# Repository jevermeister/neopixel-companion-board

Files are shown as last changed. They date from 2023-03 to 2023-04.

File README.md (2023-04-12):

# Neopixel companion board

This is a board to control and power Neopixels (WS2812 and derivatives) using a separate microcontroller.

**Please note that the board doesn't feature any fuses to keep it compact. If for whichever reasons you get a short, bad things may happen!
If in doubt, add a 5A fuse after the microfit connector for additional safety**

To reliably control and power also large strips, the board does a couple of things:

* A 1000uF capacitor for each strip to buffer initial power spikes which may cause the Neopixel controller to brownout due to voltage drops (which would cause the strip to now show anything)
* A 4.7k pulldown resistor for each microcontroller pin to make sure these pins are not floating. While most microcontrollers have integrated pulldowns which could be activated, this won't hurt and ensure a stable communication.
* A level shifter (SN74AHCT125D) as Neopixel expect 5V logic levels while most 32-bit microcontrollers have only 3.3V. Often they also work with 3.3V voltage but not always, that is why we make sure they will with a level shifter. In case you already have 5V logic level - This won't hurt at least and the level shifter is able to deal with it.
* Provide high current connectors. Each strip is connected using Molex Microfit 3.0 connectors which are rated up to 5A. The board itself is connected with screw terminals rated up to 18A.

I already put LCSC/JLCPCB part numbers in the design so you should be able to order these either assembled or know which parts to get.
Please note that I used a TE 796949-2 screw terminal on my PCB which is not available at LCSC so the one I put in there should also fit and work but I didn't test it.

How to wire it:
* Attach microcontroller pins to the JST-XH terminal labeled 1 2 3 4, these correspond to the J1 to J4 molex connectors

Best case those are pins which go straight to the microcontrollers without anything in between. I used PE7 to PE10 located at the EXP1 connector of my BigTreeTech Octopus Pro 1.0
* Attach a 5V power supply (don't try anything higher or the capacitors *will* pop) to the screw terminals, polarity is shown on the board

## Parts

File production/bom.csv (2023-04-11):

Designator | Footprint | Quantity | Value | LCSC Part #
C1, C2, C3, C4 | CP_Radial_D8.0mm_P3.50mm | 4 | 1000 uF | C106511
J1 | Molex_Micro-Fit_3.0_43650-0315_1x03_P3.00mm_Vertical | 1 | PXL_1_Output | C293546
J2 | Molex_Micro-Fit_3.0_43650-0315_1x03_P3.00mm_Vertical | 1 | PXL_2_Output | C293546
J3 | Molex_Micro-Fit_3.0_43650-0315_1x03_P3.00mm_Vertical | 1 | PXL_3_Output | C293546
J4 | Molex_Micro-Fit_3.0_43650-0315_1x03_P3.00mm_Vertical | 1 | PXL_4_Output | C293546
J5 | 796949-2 | 1 | VIN | C430601
J6 | JST_XH_B4B-XH-A_1x04_P2.50mm_Vertical | 1 | PXL_Input | C144395
R1, R2, R3, R4 | 1206 | 4 | 4.7K | C104821
U1 | SN74AHCT125D | 1 | SN74AHCT125D | C155176

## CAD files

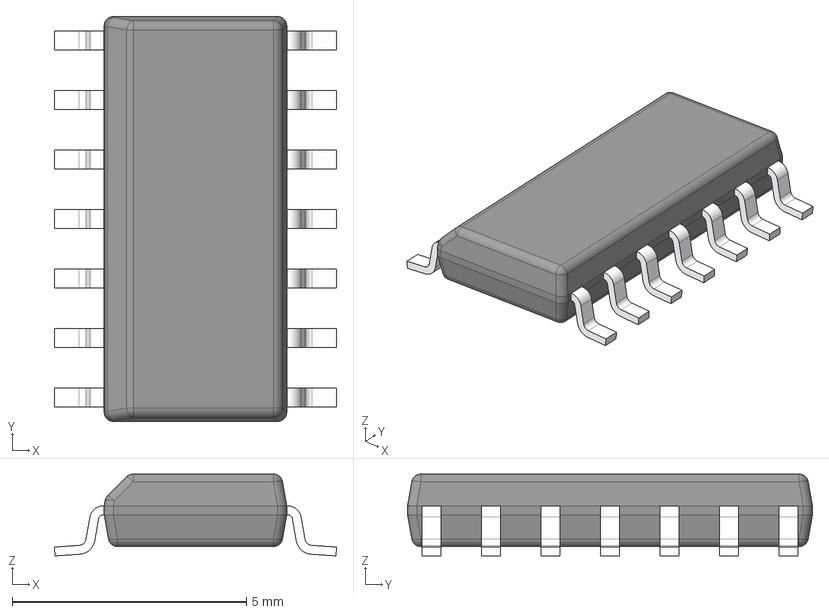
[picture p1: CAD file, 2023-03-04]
D0014A.stp
6.03 x 8.65 x 1.75 mm
BODY-SO
LEAD-SO x 14
PIN1-ID

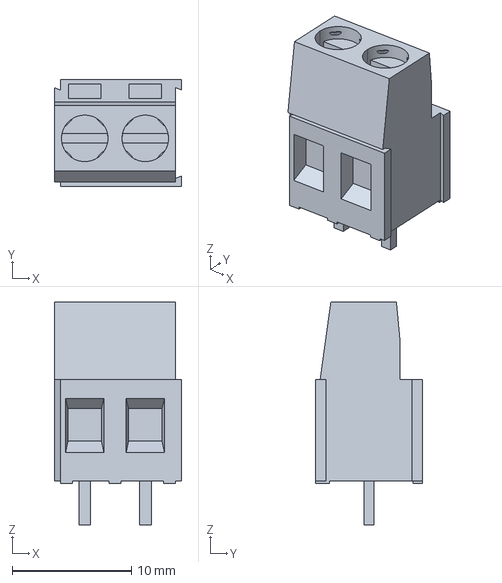
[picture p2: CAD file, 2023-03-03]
c-796949-2-c-3d.stp
10.7 x 9.00 x 18.7 mm

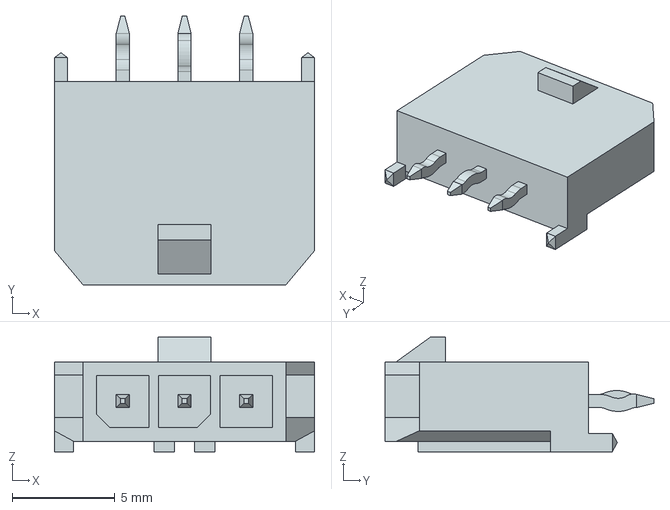
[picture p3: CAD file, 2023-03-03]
436500315.stp
12.7 x 13.1 x 5.57 mm

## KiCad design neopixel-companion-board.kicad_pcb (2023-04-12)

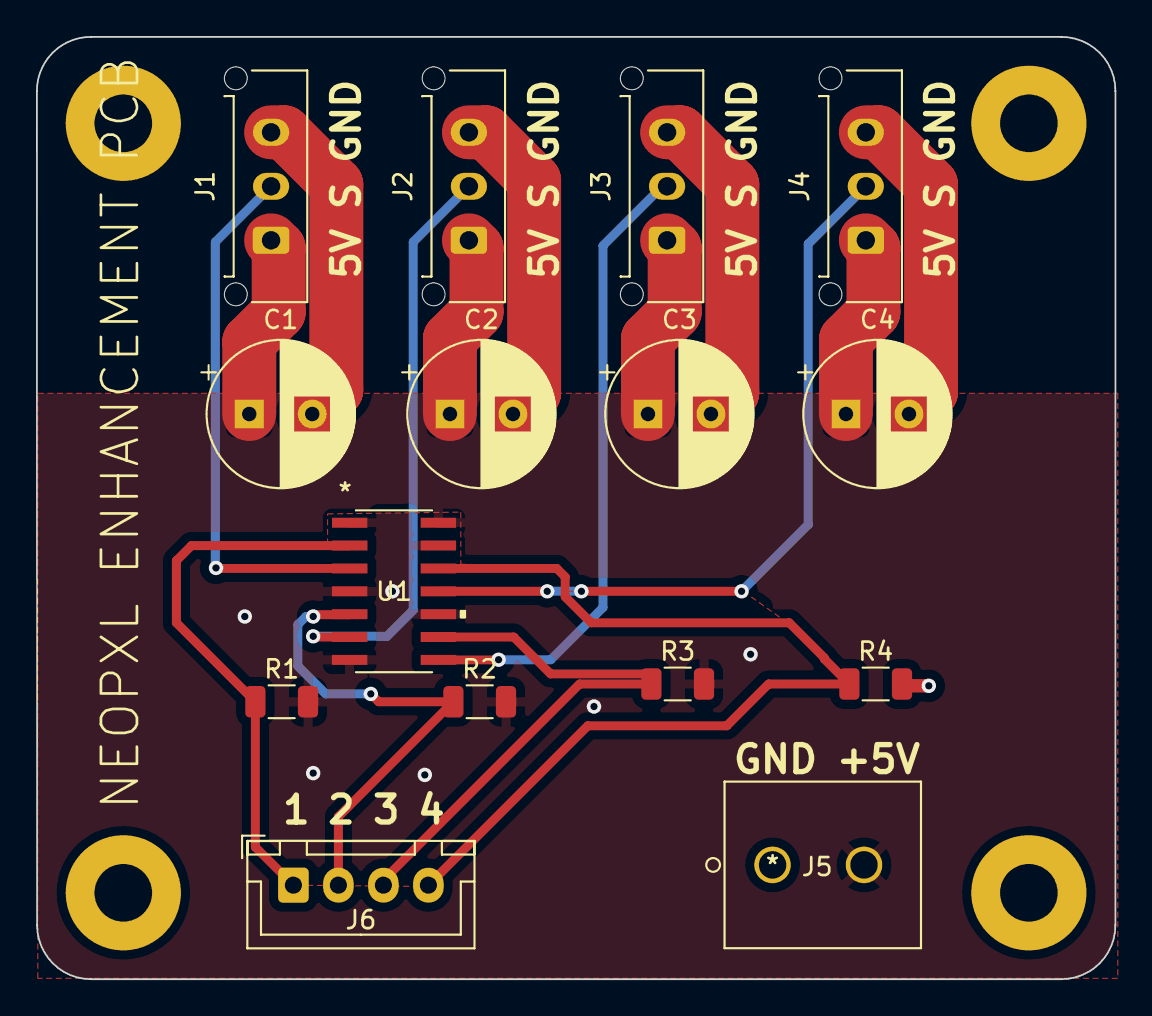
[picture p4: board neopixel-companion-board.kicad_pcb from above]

Board: 2 copper layers, 59.9 x 52.4 mm, 15 parts (0 on the bottom side), 10 nets.

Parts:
C1, C2, C3, C4: 1000 uF; CP_Radial_D8.0mm_P3.50mm
J1: PXL_1_Output; Molex_Micro-Fit_3.0_43650-0315_1x03_P3.00mm_Vertical
J2: PXL_2_Output; Molex_Micro-Fit_3.0_43650-0315_1x03_P3.00mm_Vertical
J3: PXL_3_Output; Molex_Micro-Fit_3.0_43650-0315_1x03_P3.00mm_Vertical
J4: PXL_4_Output; Molex_Micro-Fit_3.0_43650-0315_1x03_P3.00mm_Vertical
J5: VIN; 796949-2
J6: PXL_Input; JST_XH_B4B-XH-A_1x04_P2.50mm_Vertical
R1, R2, R3, R4: 4.7K; R_1206_3216Metric
U1: SN74AHCT125D

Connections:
+5V: C1.1, C2.1, C3.1, C4.1, J1.1, J2.1, J3.1, J4.1, J5.2, U1.14 (VCC)
GND: C1.2, C2.2, C3.2, C4.2, J1.3, J2.3, J3.3, J4.3, J5.1, R1.2, R2.2, R3.2, R4.2, U1.1 (*1OE), U1.4 (*2OE), U1.7 (GND), U1.10 (*3OE), U1.13 (*4OE)
Neopixel_1: J6.1, R1.1, U1.2 (1A)
Neopixel_1_5V: J1.2, U1.3 (1Y)
Neopixel_2: J6.2, R2.1, U1.5 (2A)
Neopixel_2_5V: J2.2, U1.6 (2Y)
Neopixel_3: J6.3, R3.1, U1.9 (3A)
Neopixel_3_5V: J3.2, U1.8 (3Y)
Neopixel_4: J6.4, R4.1, U1.12 (4A)
Neopixel_4_5V: J4.2, U1.11 (4Y)

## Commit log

2023-02-24 Moved location
    [neopixel-companion-board.kicad_pcb, neopixel-companion-board.kicad_sch]
2023-03-03 initial beta stuff
    [neopixel-companion-board.kicad_pcb, neopixel-companion-board.kicad_sch]
2023-03-03 Added molex connector models and text
    [436500315.stp, neopixel-companion-board.kicad_pcb]
2023-03-03 Changed connector and added library files
    [c-796949-2-c-3d.stp, neopixel-companion-board.kicad_pcb, neopixel-companion-board.kicad_sch]
2023-03-04 Replaced single schmitt triggers with a 4 bit level shifter
    [D0014A.stp, neopixel-companion-board.kicad_pcb, neopixel-companion-board.kicad_sch]
2023-04-11 Added LCSC parts and gerbers
    [bom.csv, designators.csv, neopixel-companion-board.kicad_pcb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]
2023-04-12 Added LCSC part numbers
    [neopixel-companion-board.kicad_pcb]

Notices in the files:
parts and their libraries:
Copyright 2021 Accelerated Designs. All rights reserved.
